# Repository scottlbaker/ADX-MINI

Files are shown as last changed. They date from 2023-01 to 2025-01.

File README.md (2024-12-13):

## Summary

ADX-MINI, ADX-MI2 and ADX-MI3 (Arduino Digital Tranceivers)

## Description

The ADX-MINI is a simple digital HF tranceiver that uses a CD2003 receiver chip
and a Class-E QRP transmitter. It is meant to be used with the WSJT/X software
and a host computer (or phone or tablet).

The ADX-MI2 is an enhanced version of ADX-MINI that adds onboard USB soundcard capabilities. This simplifies the connections to the host computer. The ADX-MI2 and ADX-MINI are firmware compatible.

The ADX-MI3 replaces the UI pushbuttons and status LEDs with an OLED and additional CAT commands. Because of the UI and CAT changes, the ADX-MI3 is not firmware compatible with the ADX-MINI and ADX-MI2.

## Contributors

* Scott L Baker

* If you like my designs and would like to support my work: https://buymeacoffee.com/scottlbaker

## Acknowledgement

The ADX-MINI is inspired by and derived from the ADX, ADX-UNO, and ADX-POCKET
projects by WB2CBA. More info about the ADX project can be found here:
https://antrak.org.tr/blog/adx-arduino-digital-transceiver

## License

See the **LICENSE** file in this repository

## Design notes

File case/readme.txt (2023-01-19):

PCB  .. top and bottom plate PCBs

3D   .. stl files for standoffs and buttons

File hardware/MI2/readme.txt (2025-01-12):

MI2 = adx-mini + sound card chip and USB hub

  rev 1.2 -- USB-C -- PRODUCTION VERSION
  rev 1.3 -- Added USB-C 5.1k CC1 and CC2 resistors

change USB-C connector from C2765186 to C165948

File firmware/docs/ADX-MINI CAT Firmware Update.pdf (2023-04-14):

# ADX-MINI CAT Firmware Update

Document Revision 1.0

April 12, 2023

Acknowledgement: The ADX-MINI is derived from the ADX, and ADX-UNO projects by WB2CBA. More info about the ADX project can be found here: https://antrak.org.tr/blog/adx-arduino-digital-transceiver

## Table of Contents

## Introduction

CAT control is supported by the ADX-MINI firmware starting with firmware version 1.04b. A small subset of TS2000 CAT command is implemented. The main purpose of CAT support for the ADX-MINI is to update the VFO frequency when band or mode changes are made in the WSJT-X control window.

## Implemented Commands

The following CAT commands are implemented in the ADX-MINI firmware.

Cmd | Type | Operation | Operation
AI | R | Auto-Information | Returns 0
FA | R/W | Frequency | Sets and reads back ADX frequency
IF | R | Radio Status | Returns ADX frequency and TX status
ID | R | Radio ID | Returns 019 = Kenwood TS2000
MD | R | Radio Mode | Returns 2
PS | R | Power-on status | Returns 1
TX | R | Transmit | Returns 0 and sets ADX TX LED
RX | R | Receive | Returns 0 and clears ADX TX LED

Note: the TX and RX commands do not control the transmit. Transmit is always controlled by VOX whether in normal mode or CAT mode

## Enabling CAT

When the ADX-MINI is first powered up CAT is not enabled. CAT can be enabled by pressing and holding the “>” button until the LEDs light up sequentially in a right to left Cylon sequence.

## Disabling CAT

When the ADX-MINI is in CAT enabled mode, CAT can be disabled by pressing and holding the “>” button until the LEDs light up sequentially in a left to right Cylon sequence.

# Appendix

WSJT-X Settings

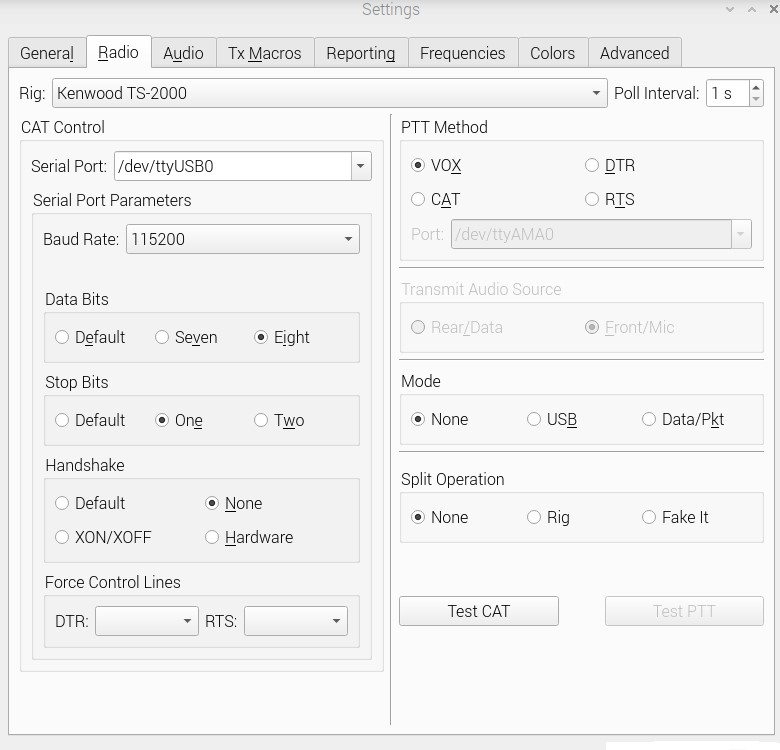
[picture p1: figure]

USB Serial Port Connection

Depending on which version of ADX-MINI that you have you may need to connect a USB-to-serial converter, like this one

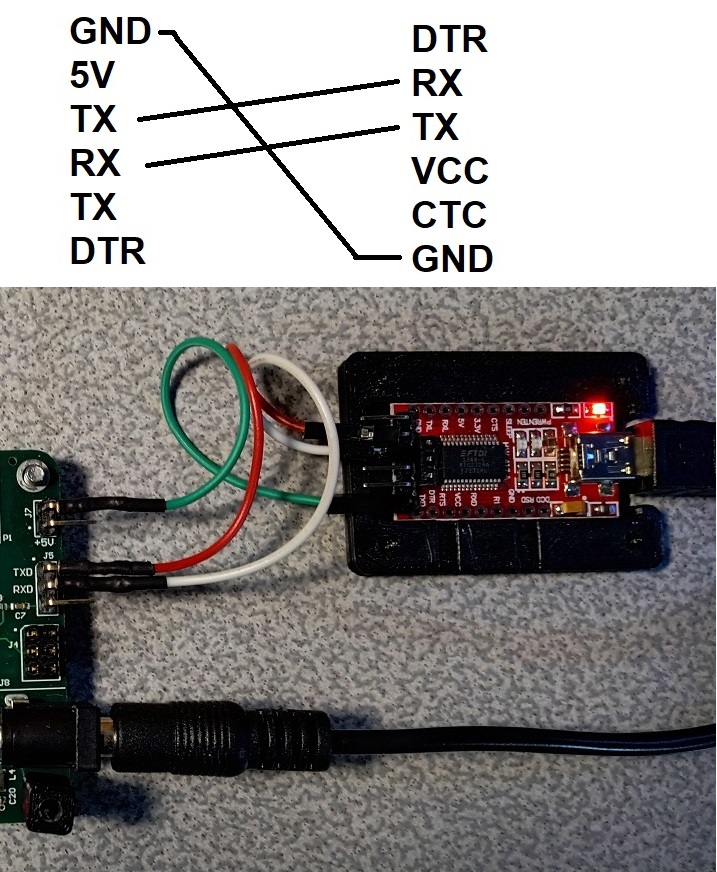
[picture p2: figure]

If you have a new ADX-MINI (V1.5) then the USB-to-serial converted is onboard.

Note: Only 3 wires are needed (TX, RX, and GND). Do NOT connect the adapter 5V to the ADX-MINI 5V.

Testing the Serial Port

To test the serial port you first need to determine which serial port has been assigned. This will differ depending on whether you are using Window or Linux. I’m not going to give a tutorial here. YouTube is your friend.

Once you have determine the serial port, then you can use a terminal program like PuTTY to verify that you are connected and able to communicate with the ADX-MINI. PuTTY is available on either Windows or Linux. Here is a PuTTY screen shot showing CAT command communication:

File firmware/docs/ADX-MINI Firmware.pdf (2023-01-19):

# ADX-MINI Firmware

Document Revision 0.02 – Preliminary --

November 17, 2022

Acknowledgement: The ADX-MINI is derived from the ADX, and ADX-UNO projects by WB2CBA. More info about the ADX project can be found here: https://antrak.org.tr/blog/adx-arduino-digital-transceiver

This firmware update is based on ADX-UNO firmware. The main difference is adding band encoding so that more than 4 bands can be supported without requiring the user to reprogram the radio.

It is recommended for builders of the ADX-MINI to also download the ADX-UNO manual which can be found here:
https://github.com/WB2CBA/ADX-UnO-V1.3

## Table of Contents

## Changes from ADX_UNO Firmware

Band Encoding

The ADX radio has a simple UI with 5 status LEDs. In the original code 4 of these LEDs are used for indicating both the 4 supported modes (WSPR, JS8, FT4, and FT8) and 4 bands (80m, 40m, 20m, and 17m). Other bands are supported but require the user to change the source code in order to choose a different 4 bands.

The main purpose of this new firmware version is to add all band support and the only way to do that is by encoding the band selection. The encoding is listed in the appendix of this document.

Factory Reset

This is a new feature. By pressing the “<” pushbutton during power-up, the ADX will use the factory default user settings for mode, band, and si5351 calibration.

I usually use this feature when programming a new radio. If you press both the “<” and “>” pushbuttons during power up, you will enter calibration mode with factory reset values.

Manual TX

Manual TX is not something that the user does (except during Antenna tuning or bench-mode power measurements) and it can potentially damage the PA if the TX button is accidentally pressed. Therefore this firmware version requires a long-press of the TX pushbutton in order to activate a manual TX.

## Calibration

The calibration steps are:

1) Connect a scope or frequency counter to the CLK2/CAL testpoint
2) Power OFF and press “<” and “>” (or just “>”) ** and then power ON
3) After the WSPR and FT8 LEDs flash release the pushbutton(s)
4) Now you are in calibration mode and “<” and “>” can be used to adjust the CLK2/CAL frequency to exactly 1 MHz
5) Press the TX switch to save the calibration and exit calibration mode

** NOTE
When calibrating a new radio it is recommended that you press both “<” and “>” pushbuttons during power up. This will enter calibration mode with factory reset values. If subsequent calibration is required then you should press only the “>” pushbutton to enter calibration mode while preserving the previous cal settings.

## Operating

Warning: Never operate the ADX-MINI without a band module in place or without a suitable antenna or dummy load. The class-E PA is susceptible to damage under these conditions. In other words, it you press the TX button without the proper band module installed you will surely let the magic smoke out of the BS170 PA FETs.

Digital Mode Selection

The ADX powers up in this mode. While in this mode a short click of “<” or “>” will cycle through the 4 supported digital modes:

- Digital Mode 1 = WSPR
- Digital Mode 2 = JS8
- Digital Mode 3 = FT4
- Digital Mode 4 = FT8

A short click to the TX pushbutton will save the current radio mode to eeprom. A long press of the TX pushbutton will activate a manual TX (for tuning).
A long press of either the “<” or “>” pushbutton will enter the band select mode.

Band Selection

While in band select mode, a short click of “<” or “>” will cycle through the bands: 160m, 80m, 60m, 40m, 30m, 20m, 17m, 15m, 12m, 10m, and 6m. Refer to the band encoding table in the appendix of this document.

A short click to the TX pushbutton will save the current band to eeprom.
A long press of the TX pushbutton will activate a manual TX (for tuning).
A long press of either the “<” or “>” pushbutton will exit the band select mode.

# Appendix

Band Encoding Table

WSPR | JS8 | TX | FT4 | FT8
LED | LED | LED | LED | LED
160m | 1 | 1 | x | 1 | 1 | Group 3 | Band 3
80m | 1 | 1 | x | 1 | 0 | Group 3 | Band 2
60m | 1 | 1 | x | 0 | 1 | Group 3 | Band 1
40m | 1 | 1 | x | 0 | 0 | Group 3 | Band 0
30m | 1 | 0 | x | 1 | 1 | Group 2 | Band 3
20m | 1 | 0 | x | 1 | 0 | Group 2 | Band 2
17m | 1 | 0 | x | 0 | 1 | Group 2 | Band 1
15m | 0 | 1 | x | 1 | 1 | Group 1 | Band 3
12m | 0 | 1 | x | 1 | 0 | Group 1 | Band 2
10m | 0 | 1 | x | 0 | 1 | Group 1 | Band 1
6m | 0 | 0 | x | 1 | 1 | Group 0 | Band 3

Note: This band encoding was designed so that at least two LEDs are ON for any band which helps the user differentiate band selection from radio mode selection, since during Radio mode selection only one LED is on for each radio mode (WSPT/JS8/FT4/FT8).

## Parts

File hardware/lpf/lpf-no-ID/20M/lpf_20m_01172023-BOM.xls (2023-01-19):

Designator | Comment | Footprint | Quantity | Part Number
C1 | 68pF | 6-0805 | 1 | C527207
C2,C4,C6 | 470pF | 6-0805 | 3 | C513677
C5 | 150pF | 6-0805 | 1 | C152846

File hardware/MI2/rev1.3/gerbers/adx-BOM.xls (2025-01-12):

Designator | Comment | Footprint | Quantity | Part Number
C1,C4,C8,C14,C15,C16,C17,C18,C19,C20,C21,C22,C23,C24,C25,C26,C28,C29,C30,C31,C32,C35,C36,C37,C38,C44,C45,C46,C47,C48,C49 | 10uF | 3-0603 | 31 | C344022
C2 | 1nF | 3-0603 | 1 | C106246
C3,C5,C6,C7,C12,C13,C27,C33,C34,C39,C40,C41,C42,C43,C50 | .1uF | 3-0603 | 15 | C113803
C9 | 680pF | 3-0603 | 1 | C1630
C10,C11 | .01uF | 3-0603 | 2 | C100042
D1,D2,D3,D4,D5 | LED | 3-0603 | 5 | C434419
D6 | BAV23S | SOT23-3 | 1 | C44345
D7 | 1SMA4756 | ZENER-DO214 | 1 | C438374
D8 | SS14 | SOD123 | 1 | C2909920
J5 | USB-C | USB-C | 1 | C165948
L1 | 100uH | 6-0805 | 1 | C223180
L2 | 1uH | 3-0603 | 1 | C22037
Q1 | BS170 | SOT23-3 | 1 | C558098
R1,R2,R3,R4,R5,R6,R7,R14 | 10.0K | 3-0603 | 8 | C191318
R8 | 100 | 3-0603 | 1 | C22775
R9,R10,R11,R12,R13,R16 | 1K | 3-0603 | 6 | C14676
R15 | 11K | 3-0603 | 1 | C336851
R17,R18 | 4.7K | 3-0603 | 2 | C105428
R19 | 1.5K | 3-0603 | 1 | C22843
R20,R21 | 5.1K | 3-0603 | 2 | C105580
S1,S2,S3 | Push Button | PB1 | 3 | C221880
U1 | ATMEGA328 | ATMEG328 | 1 | C14877
U3 | 74ACT244 | TSSOP-20 | 1 | C6930
U4 | XC6206-3.3 | SOT23-3 | 1 | C347376
U5 | Si5351A | MSOP-10 | 1 | C1509083
U6 | CM108 | LQFP48 | 1 | C371347
U7 | SL21S | SSOP16-2 | 1 | C2684433
U8 | CH340E | MSOP-10 | 1 | C99652
Y1 | 16MHz | Xtal_SMT1 | 1 | C13738
Y2 | 25MHz | Xtal_SMT | 1 | C9006
Y3,Y4 | 12MHz | Xtal_SMT | 2 | C9002

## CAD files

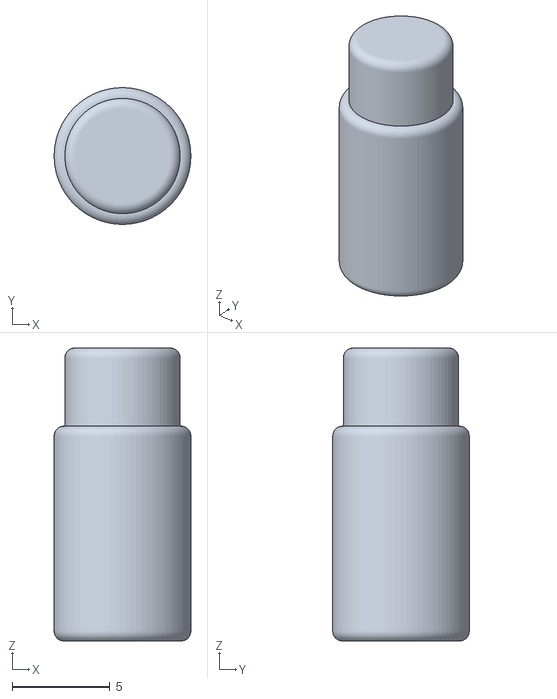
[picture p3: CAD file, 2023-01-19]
case/3D/button.stl
7.00 x 6.99 x 15.0

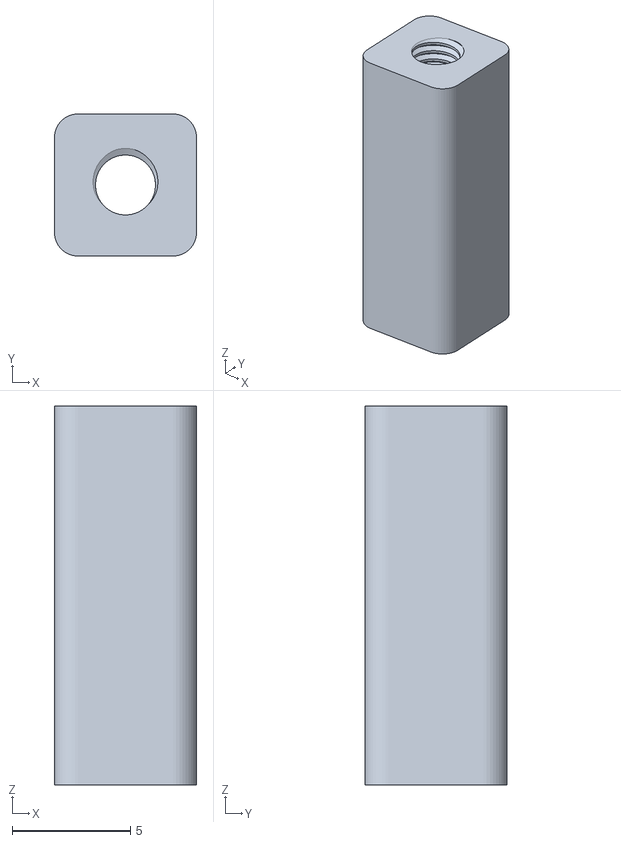
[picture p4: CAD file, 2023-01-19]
case/3D/standoff.stl
6.00 x 6.00 x 16.0

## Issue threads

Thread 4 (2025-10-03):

ADX MINI burning down?

MachinistEt1964, 2025-10-03:
Okay here we go, tryed to build the ADX mini for several times, but when i connect to the power supply(3 18650) then the L4 start to burn??. So i build it again and by the 3 time building, i first put all the resistors and the caps on the pcb and connect it to power, no problems, thinking okay good. Then the 1117 5 and 3 volts, again no problems, then the ATmega 328, and yep the L4 burns again?? So i can't finf what the problem is?? it is well soldered, no shorts on the solderings, so can it be that JLPCB made afailure in the pcb??
Regards
Rene
PD0REB
rmvanb@gmail.com

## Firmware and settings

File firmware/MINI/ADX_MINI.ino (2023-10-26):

// ============================================================================
//
// ADX_MINI.ino  ::  ADX-MINI Control Program with CAT control
//
// This control program was derived from the ADX control program.
// It is compatible with ADX, ADX-UNO, and ADX-MINI hardware.
// Supported bands are: 160M/80M/60M/40M/30M/20M/17M/15M/12M/10M/6M
// The user interface is described in a separate document.
//
// (c) Scott Baker KJ7NLA
//
//  Arduino IDE settings:
//  board: Arduino UNO
//  bootloader: no bootloader
//  programmer: AVRISP mkII
//
// Libraries
// ---------
// Arduino Wire.h   I2C library - built-into Arduino IDE
// Arduino EEPROM.h library     - built-into Arduino IDE
// Si5351 library               - by Milldrum and Myers
//
// Acknowledgement
// ---------------
// The Arduino Digital Transceiver (ADX) hardware was designed by WB2CBA
// The ADX is a simple QRP radio in both its hardware implmentation and
// its user interface. Yet it is highly capable when paired with
// the WSJT-X software.  Thanks Barb !!
//
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
// ============================================================================

#define DEBUG1    0                     // set to 1 for debug level 1
#define DEBUG2    0                     // set to 1 for debug level 2
#define VERSION   "ADX-MINI 1.04d"      // firmware version
#define DATE      "Jul 29 2023"         // firmware date
#define NOTE1     "with CAT support"    // firmware notes

// Arduino Pins
#define LTSW      2     // PD2   UI pushbutton <
#define RTSW      3     // PD3   UI pushbutton >
#define TXSW      4     // PD4   UI pushbutton TX
#define TXXLED   13     // PB5   TX   status LED
#define WSPLED    9     // PB1   WSPR status LED
#define JS8LED   10     // PB2   JS8  status LED
#define FT4LED   11     // PB3   FT4  status LED
#define FT8LED   12     // PB4   FT8  status LED
#define RXGATE    8     // PB0   RX Gate
#define ACMP      7     // PD7   analog comparator

// generic
#define OFF   0
#define ON    1
#define NO    0
#define YES   1
#define RX    0
#define TX    1
#define FALSE 0
#define TRUE  1
#define RIGHT 0
#define LEFT  1

#include <Wire.h>
#include <EEPROM.h>
#include "si5351.h"

// string prototype defs
char getc();
char gnac();
void getsemi();
char gcal(char ch);
uint8_t len(char *str);
uint8_t cmpstr(char *dst, char *src);
uint8_t alpha(char ch);
uint8_t numeric(char ch);
void catstr(char *dst, char c);
void uppercase(char *str);
uint32_t fs2int(char *str);

// prototype defs
void print_version();
void wait_ms(uint16_t dly);
void clrLED();
void blinkLED(uint8_t pin, uint8_t x);
void blinkTX();
void setLED(uint8_t data);
void display_band();
void display_mode();
void blink_band();
void blink_mode();
void blink_both();
void set_all();
void clr_all();
void blink_all();
void cylon(uint8_t left);
void mode_assign();
void band_assign();
void band_select();
void freq2band();
void manualTX();
void si5351_cal();
void FSK_tone();
void check_VOX();
void rx_mode();
void check_UI();
void check_CAT();
void CAT_VFO();
void CAT_control();
void save_eeprom();
void read_eeprom();
void init_VFO();
void init_timer();
void initPins();
void print_band();
void print_mode();
void print_cat_mode();
void print_cal_data();
void factory_reset();
void calibrate_mode();

// eeprom addresses
#define DATA_ADDR    10
#define MODE_ADDR    20
#define BAND_ADDR    30
#define CATX_ADDR    40

// delay times (ms)
#define DLY1        250
#define DEBOUNCE     20

#define MS_LONG     300  // long press
uint32_t t0;             // event timer

// read pushbutton switches
#define LT_PRESSED  !digitalRead(LTSW)
#define RT_PRESSED  !digitalRead(RTSW)
#define TX_PRESSED  !digitalRead(TXSW)

uint32_t base_freq;

uint32_t F_FT8;
uint32_t F_FT4;
uint32_t F_JS8;
uint32_t F_WSP;

// button events
#define NONE       0x00  // no event
#define CLICK      0x01  // click
#define LONG       0x02  // long press

uint8_t event = NONE;

// Si5351 xtal frequency (25 MHz)
#define SI5351_REF  25000000UL

// band groups
#define GROUP3  0xc
#define GROUP2  0x8
#define GROUP1  0x4
#define GROUP0  0x0

// band within group
#define XBAND3  0x3
#define XBAND2  0x2
#define XBAND1  0x1
#define XBAND0  0x0

#define BAND160  11
#define BAND80   10
#define BAND60    9
#define BAND40    8
#define BAND30    7
#define BAND20    6
#define BAND17    5
#define BAND15    4
#define BAND12    3
#define BAND10    2
#define BAND06    1
#define UNKNOWN   0

// encoded bands
#define ENC160m GROUP3|XBAND3
#define ENC80m  GROUP3|XBAND2
#define ENC60m  GROUP3|XBAND1
#define ENC40m  GROUP3|XBAND0
#define ENC30m  GROUP2|XBAND3
#define ENC20m  GROUP2|XBAND2
#define ENC17m  GROUP2|XBAND1
#define ENC15m  GROUP1|XBAND3
#define ENC12m  GROUP1|XBAND2
#define ENC10m  GROUP1|XBAND1
#define ENC6m   GROUP0|XBAND3
#define ENC0m   GROUP0|XBAND0

const int8_t bandENC[12] = {
 ENC0m,  ENC6m,  ENC10m, ENC12m, ENC15m,
 ENC17m, ENC20m, ENC30m, ENC40m, ENC60m,
 ENC80m, ENC160m };

// calibration data
#define CAL_DATA_INIT  64000ULL
uint32_t cal_data = CAL_DATA_INIT;

#define MAX_MODE 8
#define MIN_MODE 1
#define MAX_BAND 11
#define MIN_BAND 1

#define WSP_MODE 8
#define JS8_MODE 4
#define FT4_MODE 2
#define FT8_MODE 1

uint8_t mode = FT8_MODE;
uint8_t band = BAND20;
uint8_t cat_mode = OFF;

Si5351 si5351;

#define CPUXTL  1600000000ULL // CPU clock
#define MAXCNT  64000  // max event period
#define MAXVOX  15     // VOX timeout (ms)

volatile uint8_t  d2ICR = FALSE;
volatile uint8_t  doFSK = NO;
volatile uint16_t d1;
volatile uint16_t d2;

// timer1 input capture interrupt routine
ISR (TIMER1_CAPT_vect) {
  // check if d2 is valid
  if (!d2ICR) {
    d2 = ICR1;
    d2ICR = TRUE;
    doFSK = NO;
  } else {
    d1 = d2;
    d2 = ICR1;
    doFSK = YES;
  }
}

// read char from the serial port
char getc() {
  while (!Serial.available());
  return(Serial.read());
}

// get next alpha char from serial buffer
char gnac() {
  char ch;
  uint16_t tc = 0;  // for timeout
  while (TRUE) {
    if (Serial.available()) {
      ch = Serial.read();
      if (alpha(ch)) return(ch);
    } else {
      if (tc++ > 1024) return('z');
    }
  }
}

// wait for semicolon from serial buffer
void getsemi() {
  char ch;
  while (TRUE) {
    if (Serial.available()) {
      ch = Serial.read();
      if (ch == ';') return;
    }
  }
}

// get + or - char from serial buffer
char gcal(char ch) {
  char new_ch;
  uint16_t tc = 0;  // for timeout
  while (TRUE) {
    if (Serial.available()) {
      new_ch = Serial.read();
      if ((new_ch=='+')||(new_ch=='-')||
          (new_ch=='=')||(new_ch=='.')){
        return(new_ch);
      }
    } else {
      if (tc++ > 1024) return(ch);
    }
  }
}

// return the length of string
uint8_t len(char *str) {
  uint8_t i=0;
  while (str[i++]);
  return i-1;
}

// compare command
uint8_t cmpstr(char *x, char *y) {
  if ((x[0] == y[0]) && (x[1] == y[1])) return(1);
  else return(0);
}

uint8_t alpha(char ch) {
  if ((ch >= 'a') && (ch <= 'z')) return(1);
  if ((ch >= 'A') && (ch <= 'Z')) return(1);
  return(0);
}

uint8_t numeric(char ch) {
  if ((ch >= '0') && (ch <= '9')) return(1);
  return(0);
}

// concatenate a character to a string
void catstr(char *dst, char ch) {
  uint8_t strlen= len(dst);
  dst[strlen++] = ch;
  dst[strlen] = '\0';
}

// convert command to upper case
void uppercase(char *str) {
  if ((str[0] >= 'a') && (str[0] <= 'z')) str[0] -= 32;
  if ((str[1] >= 'a') && (str[1] <= 'z')) str[1] -= 32;
}

// convert frequency string to integer
uint32_t fs2int(char *str) {
  uint32_t tmp = 0;
  uint32_t pwr10 = 1;
  char ch;
  for (uint8_t i=10; i>2; i--) {
    ch = str[i] - 48;
    tmp += ch * pwr10;
    pwr10 = ((pwr10<<3)+(pwr10<<1));
  }
  return(tmp);
}

// print the firmware version
void print_version() {
  Serial.println('\n');
  Serial.println(VERSION);
  Serial.println(DATE);
  Serial.println(NOTE1);
}

// send a string
void send(char *str) {
  getsemi(); // get semicolon
  Serial.print(str);
}

// interruptable delay
void wait_ms(uint16_t dly) {
  uint32_t curTime = millis();
  uint32_t endTime = curTime + dly;
  while(curTime < endTime) {
    delayMicroseconds(100);
    curTime = millis();
  }
}

// wait for all buttons released
void wait4buttons() {
  while ((RT_PRESSED)||(LT_PRESSED)||(TX_PRESSED));
  delay(DEBOUNCE);
}

// clear all mode LEDs
void clrLED() {
  digitalWrite(FT8LED, OFF);
  digitalWrite(FT4LED, OFF);
  digitalWrite(JS8LED, OFF);
  digitalWrite(WSPLED, OFF);
}

// blink an LED
void blinkLED(uint8_t pin, uint8_t x) {
  uint8_t state=1;
  for (uint8_t i=0; i<(x<<1); i++) {
    digitalWrite(pin, state);
    state = !state;
    delay(DLY1);
  }
}

// blink the TX LED
void blinkTX() {
  clrLED();
  blinkLED(TXXLED, 2);
}

// set LEDs with data
void setLED(uint8_t data) {
  digitalWrite(FT8LED, bitRead(data, 0));
  digitalWrite(FT4LED, bitRead(data, 1));
  digitalWrite(JS8LED, bitRead(data, 2));
  digitalWrite(WSPLED, bitRead(data, 3));
}

// set LEDs with the encoded band
void display_band() {
  uint8_t data = bandENC[band];
  setLED(data);
}

// set LEDs with the digital mode
void display_mode() {
  setLED(mode);
}

// blink the selected band
void blink_band() {
  for (uint8_t i=0; i<2; i++) {
    clrLED();
    delay(DLY1);
    display_band();
    delay(DLY1);
  }
}

// blink the selected mode
void blink_mode() {
  for (uint8_t i=0; i<2; i++) {
    clrLED();
    delay(DLY1);
    display_mode();
    delay(DLY1);
  }
}

// blink band then mode
void blink_both() {
  blink_band();  // blink band on LEDs
  delay(500);
  blink_mode();  // blink mode on LEDs
}

// set all LEDs
void set_all() {
  digitalWrite(FT8LED, ON);
  digitalWrite(FT4LED, ON);
  digitalWrite(JS8LED, ON);
  digitalWrite(WSPLED, ON);
  digitalWrite(TXXLED, ON);
}

// clear all LEDs
void clr_all() {
  digitalWrite(FT8LED, OFF);
  digitalWrite(FT4LED, OFF);
  digitalWrite(JS8LED, OFF);
  digitalWrite(WSPLED, OFF);
  digitalWrite(TXXLED, OFF);
}

// blink all the LEDs
void blink_all() {
  clr_all();
  delay(500);
  set_all();
  delay(500);
  clr_all();
}

// cylon blink all the LEDs
void cylon(uint8_t left) {
  clr_all();
  delay(500);
  if (left) {
    digitalWrite(FT8LED, ON);
    delay(100);
    digitalWrite(FT4LED, ON);
    delay(100);
    digitalWrite(TXXLED, ON);
    delay(100);
    digitalWrite(JS8LED, ON);
    delay(100);
    digitalWrite(WSPLED, ON);
  } else {
    digitalWrite(WSPLED, ON);
    delay(100);
    digitalWrite(JS8LED, ON);
    delay(100);
    digitalWrite(TXXLED, ON);
    delay(100);
    digitalWrite(FT4LED, ON);
    delay(100);
    digitalWrite(FT8LED, ON);
  }
  delay(500);
  clr_all();
  delay(500);
  blink_both();  // blink band then mode on LEDs
}

// mode assignments
void mode_assign() {
  switch (mode) {
    case WSP_MODE:
      base_freq = F_WSP;
      break;
    case JS8_MODE:
      base_freq = F_JS8;
      break;
    case FT4_MODE:
      base_freq = F_FT4;
      break;
    case FT8_MODE:
      base_freq = F_FT8;
      break;
    default:
      break;
  }
  rx_mode();
}

// band frequency assignments
void band_assign() {
  switch (band) {
    case BAND160:
      // 160M band
      F_FT8 = 1842000;
      F_FT4 = 1842000;
      F_JS8 = 1842000;
      F_WSP = 1842000;
      break;
    case BAND80:
      // 80M band
      F_FT8 = 3573000;
      F_FT4 = 3575000;
      F_JS8 = 3578000;
      F_WSP = 3568600;
      break;
    case BAND60:
      // 60M band
      /*
      F_FT8 =
      F_FT4 =
      F_JS8 =
      F_WSP =
      */
      break;
    case BAND40:
      // 40M band
      F_FT8 = 7074000;
      F_FT4 = 7047500;
      F_JS8 = 7078000;
      F_WSP = 7038600;
      break;
    case BAND30:
      // 30M band
      F_FT8 = 10136000;
      F_FT4 = 10140000;
      F_JS8 = 10130000;
      F_WSP = 10138700;
      break;
    case BAND20:
      // 20M band
      F_FT8 = 14074000;
      F_FT4 = 14080000;
      F_JS8 = 14078000;
      F_WSP = 14095600;
      break;
    case BAND17:
      // 17M band
      F_FT8 = 18100000;
      F_FT4 = 18104000;
      F_JS8 = 18104000;
      F_WSP = 18104600;
      break;
    case BAND15:
      // 15M band
      F_FT8 = 21074000;
      F_FT4 = 21140000;
      F_JS8 = 21078000;
      F_WSP = 21094600;
      break;
    case BAND12:
      // 12M band
      F_FT8 = 24915000;
      F_FT4 = 24919000;
      F_JS8 = 24922000;
      F_WSP = 24924600;
      break;
    case BAND10:
      // 10M band
      F_FT8 = 28074000;
      F_FT4 = 28180000;
      F_JS8 = 28078000;
      F_WSP = 28124600;
      break;
    case BAND06:
      // 6M band
      F_FT8 = 50313000;
      F_FT4 = 50318000;
      F_JS8 = 50318000;
      F_WSP = 50293000;
      break;
  }
  mode_assign();
}

// band select
void band_select() {
  bool done = NO;
  blink_band();
  while ((LT_PRESSED)||(RT_PRESSED));  // wait for release
  delay(DEBOUNCE);
  while (!done) {
    // check the < button
    if (LT_PRESSED) {
      t0 = millis();
      event = CLICK;
      // wait for release
      while (LT_PRESSED) {
        // check for long press
        if ((millis() - t0) > MS_LONG) { event = LONG; break; }
        wait_ms(1);
      }
      delay(DEBOUNCE);
      if (event == LONG) {
        // for long press of < button
        // exit band-select mode
        done = YES;
        blink_mode();
      } else {
        // for short click of < button
        // decrement the band
        band = band - 1;
        if (band < MIN_BAND) band = MAX_BAND;
        display_band();
        band_assign();
      }
      while (LT_PRESSED);  // wait for release
      delay(DEBOUNCE);
    }
    // check the > button
    if (RT_PRESSED) {
      t0 = millis();
      event = CLICK;
      // wait for release
      while (RT_PRESSED) {
        // check for long press
        if ((millis() - t0) > MS_LONG) { event = LONG; break; }
        wait_ms(1);
      }
      delay(DEBOUNCE);
      if (event == LONG) {
        // for long press of < button
        // exit band-select mode
        done = YES;
        blink_mode();
      } else {
        // for short click of < button
        // increment the band
        band = band + 1;
        if (band > MAX_BAND) band = MIN_BAND;
        display_band();
        band_assign();
      }
      while (RT_PRESSED);  // wait for release
      delay(DEBOUNCE);
    }
    // check the tx button
    if (TX_PRESSED) {
      t0 = millis();
      event = CLICK;
      // wait for release
      while (TX_PRESSED) {
        // check for long press
        if ((millis() - t0) > MS_LONG) { event = LONG; break; }
        wait_ms(1);
      }
      if (event == LONG) {
        // for long press of TX button
        // manual TX
        manualTX();
        display_band();
      } else {
        // for short click of TX button
        // save the band to eeprom
        blinkTX();
        EEPROM.put(BAND_ADDR, band);
        while (TX_PRESSED);  // wait for release
        delay(DEBOUNCE);
        // exit band-select mode
        done = YES;
        blink_mode();
      }
    }
  }
}

// frequency to band
void freq2band() {
  band = UNKNOWN;
  mode = UNKNOWN;
  // lookup the band
  if ((base_freq > 50000000) && (base_freq < 54000000)) {
    band = BAND06;
  } else if ((base_freq > 28000000) && (base_freq < 29700000)) {
    band = BAND10;
  } else if ((base_freq > 24890000) && (base_freq < 24990000)) {
    band = BAND12;
  } else if ((base_freq > 21000000) && (base_freq < 21450000)) {
    band = BAND15;
  } else if ((base_freq > 18070000) && (base_freq < 18170000)) {
    band = BAND17;
  } else if ((base_freq > 14000000) && (base_freq < 14350000)) {
    band = BAND20;
  } else if ((base_freq > 10100000) && (base_freq < 10150000)) {
    band = BAND30;
  } else if ((base_freq >  7000000) && (base_freq <  7300000)) {
    band = BAND40;
  } else if ((base_freq >  5300000) && (base_freq <  5500000)) {
    band = BAND60;
  } else if ((base_freq >  3500000) && (base_freq <  4000000)) {
    band = BAND80;
  } else if ((base_freq >  1800000) && (base_freq <  2000000)) {
    band = BAND160;
  }
  // lookup the mode
  switch (base_freq) {
    // 160M band
    case 1840000:
      mode = FT8_MODE;
      break;
    case 1842000:
      mode = JS8_MODE;
      break;
    case 1836000:
      mode = WSP_MODE;
      break;
    // 80M band
    case 3573000:
      mode = FT8_MODE;
      break;
    case 3575000:
      mode = FT4_MODE;
      break;
    case 3578000:
      mode = JS8_MODE;
      break;
    case 3568600:
      mode = WSP_MODE;
      break;
    // 40M band
    case 7074000:
      mode = FT8_MODE;
      break;
    case 7047500:
      mode = FT4_MODE;
      break;
    case 7078000:
      mode = JS8_MODE;
      break;
    case 7038600:
      mode = WSP_MODE;
      break;
    // 30M band
    case 10136000:
      mode = FT8_MODE;
      break;
    case 10140000:
      mode = FT4_MODE;
      break;
    case 10130000:
      mode = JS8_MODE;
      break;
    case 10138700:
      mode = WSP_MODE;
      break;
    // 20M band
    case 14074000:
      mode = FT8_MODE;
      break;
    case 14080000:
      mode = FT4_MODE;
      break;
    case 14078000:
      mode = JS8_MODE;
      break;
    case 14095600:
      mode = WSP_MODE;
      break;
    // 17M band
    case 18100000:
      mode = FT8_MODE;
      break;
    case 18104000:
      mode = FT4_MODE;
      break;
    /*
    case 18104000:
      mode = JS8_MODE;
      break;
    */
    case 18104600:
      mode = WSP_MODE;
      break;
    // 15M band
    case 21074000:
      mode = FT8_MODE;
      break;
    case 21140000:
      mode = FT4_MODE;
      break;
    case 21078000:
      mode = JS8_MODE;
      break;
    case 21094600:
      mode = WSP_MODE;
      break;
    // 12M band
    case 24915000:
      mode = FT8_MODE;
      break;
    case 24919000:
      mode = FT4_MODE;
      break;
    case 24922000:
      mode = JS8_MODE;
      break;
    case 24924600:
      mode = WSP_MODE;
      break;
    // 10M band
    case 28074000:
      mode = FT8_MODE;
      break;
    case 28180000:
      mode = FT4_MODE;
      break;
    case 28078000:
      mode = JS8_MODE;
      break;
    case 28124600:
      mode = WSP_MODE;
      break;
    // 6M band
    case 50313000:
      mode = FT8_MODE;
      break;
    case 50318000:
      mode = FT4_MODE;
      break;
    /*
    case 50318000:
      mode = JS8_MODE;
      break;
    */
    case 50293000:
      mode = WSP_MODE;
      break;
  }
  // update the frequency
  si5351.set_freq(base_freq*100, SI5351_CLK1);
  display_band();
}

// manual TX
void manualTX() {
  digitalWrite(RXGATE, OFF);
  si5351.output_enable(SI5351_CLK1, 0);   // RX off
  clrLED();
  digitalWrite(TXXLED, ON);
  si5351.set_freq(base_freq*100, SI5351_CLK0);
  si5351.output_enable(SI5351_CLK0, 1);   // TX on
  while (TX_PRESSED);  // wait for release
  delay(DEBOUNCE);
  rx_mode();           // back to rx mode
}

// si5351 calibration
void si5351_cal() {
  uint32_t cal_freq = 1000000UL;
  bool done = NO;
  cat_mode = OFF;
  setLED(0b1111);   // set all LEDs while button pressed
  wait4buttons();   // wait for all buttons released
  setLED(0b1001);   // set LEDs to indicate cal mode
  si5351.drive_strength(SI5351_CLK2, SI5351_DRIVE_2MA);
  si5351.set_freq(cal_freq*100, SI5351_CLK2);
  si5351.set_clock_pwr(SI5351_CLK2, 1);
  si5351.output_enable(SI5351_CLK2, 1);
  while (!done) {
    // check the tx button
    if (TX_PRESSED) {
      // if TX pressed then
      // save the calibration data
      // and exit calibration mode
      done = YES;
      clrLED();            // clear all LEDs
      while (TX_PRESSED);  // wait for release
      delay(DEBOUNCE);
    }
    // check the > button
    else if (RT_PRESSED) {
      cal_data = cal_data - 100;
      si5351.set_correction(cal_data, SI5351_PLL_INPUT_XO);
      si5351.set_freq(cal_freq*100, SI5351_CLK2);
      delay(DEBOUNCE);
    }
    // check the < button
    else if (LT_PRESSED) {
      cal_data = cal_data + 100;
      si5351.set_correction(cal_data, SI5351_PLL_INPUT_XO);
      si5351.set_freq(cal_freq*100, SI5351_CLK2);
      delay(DEBOUNCE);
    }
  }
  si5351.output_enable(SI5351_CLK2, 0);
  si5351.set_clock_pwr(SI5351_CLK2, 0);
  EEPROM.put(DATA_ADDR, cal_data);
  blinkTX();  // blink TX LED when done
  rx_mode();  // put radio in rx mode
}

uint8_t  FSKtx = FALSE;
uint8_t  tx_status = RX;
uint32_t vox_timer;

void FSK_tone() {
  if (!doFSK) return;
  doFSK = NO;
  // noInterrupts();
  // FSK frequency measurement
  uint16_t delta = d2 - d1;  // captured event period
  vox_timer = millis();      // reset the vox timer
  if (delta < MAXCNT) {      // check for valid period
    if (!FSKtx) {
      clrLED();
      digitalWrite(TXXLED, ON);
      tx_status = TX;
      digitalWrite(RXGATE, OFF);
      si5351.output_enable(SI5351_CLK1, 0);  // RX off
      si5351.output_enable(SI5351_CLK0, 1);  // TX on
      FSKtx = TRUE;
    }
    uint32_t code_freq = CPUXTL/delta;
    si5351.set_freq(((base_freq*100) + code_freq), SI5351_CLK0);
    vox_timer = millis();    // reset the vox timer
  }
}

// if VOX timeout then return to rx mode
void check_VOX() {
  if (FSKtx && (millis() - vox_timer > MAXVOX)) {
    FSKtx = FALSE;
    d2ICR = FALSE;
    rx_mode();
    display_mode();
  }
}

// put radio in rx mode
void rx_mode() {
  digitalWrite(TXXLED, OFF);
  tx_status = RX;
  si5351.output_enable(SI5351_CLK0, 0);   // TX off
  si5351.set_freq(base_freq*100, SI5351_CLK1);
  si5351.output_enable(SI5351_CLK1, 1);   // RX on
  digitalWrite(RXGATE, ON);
}
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
void loop() {
  FSK_tone();              // measure FSK frequency
  if (FSKtx) check_VOX();  // check for VOX timeout
  if (cat_mode) check_CAT();
  else check_UI();
}

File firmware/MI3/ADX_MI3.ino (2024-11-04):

// ============================================================================
//
// ADX_MI3.ino  ::  ADX-MI3 Control Program with CAT control
//
// This control program was derived from the ADX control program.
// It is compatible with ADX-MI3 hardware.
// Supported bands are: 160M/80M/60M/40M/30M/20M/17M/15M/12M/10M/6M
// The user interface is described in a separate document.
//
// (c) Scott Baker KJ7NLA
//
// Libraries
// ---------
// i2c.h        - a simple I2C lib
// ee.h         - a simple EEPROM lib
// oled.h       - an OLED display lib
// font.h       - a font that I designed
// si5351.h     - by Milldrum and Myers
//
// Arduino IDE settings
// --------------------
// board: Arduino UNO
// bootloader: no bootloader
// programmer: AVRISP mkII
//
// Acknowledgement
// ---------------
// The Arduino Digital Transceiver (ADX) hardware was designed by WB2CBA
// The ADX is a simple QRP radio in both its hardware implmentation and
// its user interface. Yet it is highly capable when paired with
// the WSJT-X software.  Thanks Barb !!
//
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
// ============================================================================

#define VERSION   "ADX-MI3"             // firmware version
#define DATE      "Oct 29 2024"         // firmware date

// Arduino Pins
#define RXD       0      // PD0   UART RX            (pin 30)
#define TXD       1      // PD1   UART TX            (pin 31)
#define B3        2      // PD2   band ID 3          (pin 32)
#define B2        9      // PB1   band ID 2          (pin 13)
#define B1        3      // PD3   band ID 1          (pin  1)
#define B0       10      // PB2   band ID 0          (pin 14)
#define TXLED     5      // PD5   Tx LED             (pin  9)
#define ACMP      7      // PD7   analog comparator  (pin 11)
#define RXGATE    8      // PB0   Rx Gate            (pin 12)
#define VBATT    20      // ADC6  battery voltage    (pin 19)
#define BUTTON    4      // PD4   UI pushbutton      (pin  2)

#include "i2c.h"
#include "ee.h"
#include "oled.h"
#include "font.h"
#include "si5351.h"

// generic
#define OFF      0
#define ON       1
#define NO       0
#define YES      1
#define FALSE    0
#define TRUE     1
#define RX       0    // tx/rx status
#define TX       1    // tx/rx status
#define FACTORY  0    // factory reset
#define SOFT     1    // soft reset
#define SERIAL   1    // print to UART
#define LOCAL    2    // print to OLED
#define BOTH     3    // print to UART and OLED

// string prototype defs
char getc();
char gnac();
void getsemi();
char gcal(char ch);
uint8_t len(char *str);
void send(char *str);
uint8_t cmpstr(char *dst, char *src);
void catstr(char *dst, char c);
void uppercase(char *str);
uint8_t alpha(char ch);
uint8_t numeric(char ch);
void getmode();
uint32_t fs2int(char *str);

// more prototype defs
void show_version(uint8_t x);
void show_help();
void show_cal();
void show_info();
void show_debug();
void show_queue();
void show_band(char* str);
void wait_ms(uint16_t dly);
void wait_us(uint16_t dly);
void blinkLED();
void error_blink();
void FSK_tone();
void check_VOX();
void readbuf();
inline void CAT_VFO();
inline void CAT_cmd();
void save_eeprom();
void init_VFO();
void init_freq();
void init_timer0();
void init_timer1();
void init_pins();
void init_i2c();
void init_uart();
void init_oled();
void init_check();
void init_adc();
void read_adc();
void set_tx_status(uint8_t x);
void tuning_hdr();
void tuning_mode();
void manualTX();
uint8_t check_band();
uint8_t freq2band(uint32_t freq);
void update_freq(uint32_t freq);
void check_timeout();
void check_UI();
void check_CAT();
void reset_xtimer();
void refresh();
void do_reset(uint8_t soft);
void run_calibrate();

// eeprom addresses
#define DATA_ADDR    10      // calibration data
#define FREQ_ADDR    20      // frequency

// Si5351 xtal frequency (25 MHz)
#define SI5351_REF  25000000UL

// band assignments
#define BAND160  11
#define BAND80   10
#define BAND60    9
#define BAND40    8
#define BAND30    7
#define BAND20    6
#define BAND17    5
#define BAND15    4
#define BAND12    3
#define BAND10    2
#define BAND06    1
#define UNKNOWN   0

// band ID encodings
#define ID160M  0x0e
#define ID80M   0x0d
#define ID60M   0x0b
#define ID40M   0x0a
#define ID30M   0x09
#define ID20M   0x07
#define ID17M   0x06
#define ID15M   0x05
#define ID12M   0x03
#define ID10M   0x02
#define ID06M   0x01
#define IDXXM   0x0f

// band labels
const char* band_label[] = {
" ???","  6M"," 10M"," 12M"," 15M"," 17M",
" 20M"," 30M"," 40M"," 60M"," 80M","160M" };

// mode labels
const char* mode_label[] = {
"??? ","FT8 ","FT4 ","JS8 ","WSPR","JT65"};

// calibration data
#define CAL_DATA_INIT  64000ULL
uint32_t cal_data = CAL_DATA_INIT;

#define MAX_MODE 5
#define MIN_MODE 1
#define MAX_BAND 11
#define MIN_BAND 1

#define J65_MODE 5
#define WSP_MODE 4
#define JS8_MODE 3
#define FT4_MODE 2
#define FT8_MODE 1

uint8_t mode = FT8_MODE;
uint8_t band = BAND20;

// class instantiation
Si5351  si5351;
I2C     i2c;
EE      eeprom;
OLED    oled;

#define CPUXTL  1600000000ULL // CPU clock
#define MAXCNT  64000  // max event period
#define MAXVOX  15     // VOX timeout (ms)

volatile uint8_t  d2ICR = FALSE;
volatile uint8_t  doFSK = NO;
volatile uint16_t d1;
volatile uint16_t d2;

// delay times (ms)
#define DEBOUNCE          50
#define LED_BLINK        100
#define ONE_SECOND      1000
#define TWO_SECONDS     2000
#define THREE_SECONDS   3000
#define TEN_SECONDS    10000
#define HALF_MINUTE    30000
#define ONE_MINUTE     60000
#define TIMEOUT        HALF_MINUTE

// user interface macros
#define NBP  0  // no-button-pushed
#define BSC  1  // button-single-click
#define BPL  2  // button-push-long
#define DLP  3  // double-long-press
#define SLP  4  // super-long-press

#define SUPERPRESS  3500
#define XLPRESS     1200
#define LONGPRESS   500
#define UIKEY       !digitalRead(BUTTON)

// for display blank/timeout
uint8_t  display = ON;
uint32_t xtimer;

// band module ID fault detected
uint8_t band_fault;

// millisecond time
volatile uint32_t msTimer = 0;
volatile uint16_t loopCount = 0;

// timer 0 interrupt service routine
ISR(TIMER0_COMPA_vect) {
  msTimer++;
  loopCount++;
}

// timer1 input capture interrupt routine
ISR (TIMER1_CAPT_vect) {
  // check if d2 is valid
  if (!d2ICR) {
    d2 = ICR1;
    d2ICR = TRUE;
    doFSK = NO;
  } else {
    d1 = d2;
    d2 = ICR1;
    doFSK = YES;
  }
}

// read char from the serial port
char getc() {
  while (!Serial.available());
  return(Serial.read());
}

// get next alpha char from serial buffer
char gnac() {
  char ch;
  uint16_t tc = 0;  // for timeout
  while (TRUE) {
    if (Serial.available()) {
      ch = Serial.read();
      if (alpha(ch)) return(ch);
    } else {
      if (tc++ > 1024) return('z');
    }
  }
}

// wait for semicolon from serial buffer
void getsemi() {
  char ch;
  while (TRUE) {
    if (Serial.available()) {
      ch = Serial.read();
      if (ch == ';') return;
    }
  }
}
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

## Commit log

2023-01-19 added content
    [button.stl, standoff.stl, usdx-BOM.xls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]
2023-03-07 added rev1.3 files
    [adx-BOM.xls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]
2023-03-12 fixed silkscreen gerber
2023-07-01 added ADX-MI2 files
    [adx-BOM.xls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]
2023-07-02 add MI2 case top plate
2023-12-27 added MI3 rev1.2 gerbers
2024-01-02 added MI3 lpf files
    [lpf_20m_01172023-BOM.xls, lpf_mi3_20M-BOM.xls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]
2024-09-08 added rev1.3 gerbers
2024-09-08 MI2 rev1.2 gerbers
    [adx-BOM.xls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]
2024-12-29 added MI2 BOM and CPL
    [adx-BOM.xls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]
2024-12-29 update MI2 BOM with new USB-C
    [adx-BOM.xls]
2024-12-29 update MI3 gerber zip
2025-01-12 added MI2 rev1.3 gerbers
    [adx-BOM.xls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]
2026-08-03 new MI2 gerbers
2026-08-03 remove old MI2 gerbers
